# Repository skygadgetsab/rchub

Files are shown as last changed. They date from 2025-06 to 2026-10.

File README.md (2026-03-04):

# RCHub: USB-to-PPM converter with Bluetooth

RCHub lets you control
- a plane with a stick or H.O.T.A.S.;
- a car with a USB steering wheel and pedals;
- a mini-quad with a game console controller;
- and any combination of above, plus connect a [wireless bluetooth head tracker](https://github.com/ysoldak/HeadTracker)!

<table>
<tr><td>
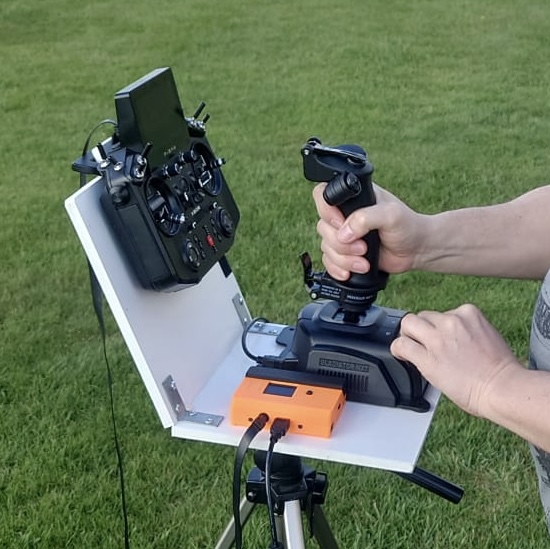
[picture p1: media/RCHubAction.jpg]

</td><td>
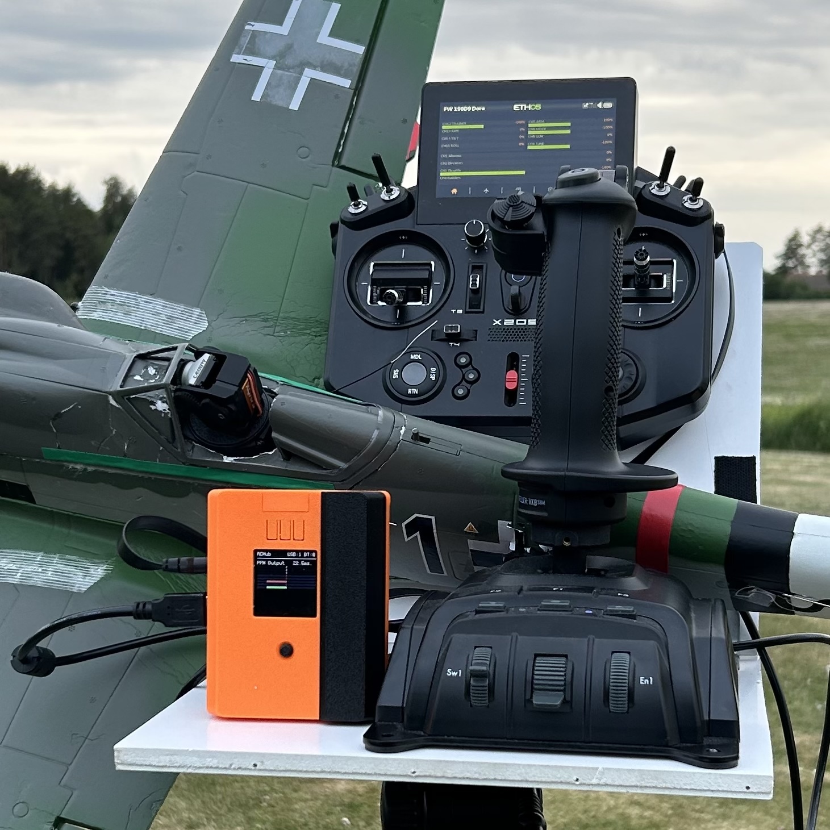
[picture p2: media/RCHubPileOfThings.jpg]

</td></tr>
</table>

## Features

- **Auto-discovery joystick devices**
  - Recognizes and pre-configures any new USB controller;
  - **Up to 8 joysticks** simultaneously.  
    _you'll need a separate USB hub for that, as RCHub has only one physical USB port._

- **Built-in display** with 5-way joystick and 3 buttons for easy configuration
  - **Up to 16 output channels** configurable directly on screen, no config file editing needed
  - **Color-coded** channel visualisations, by source
    - red - axis,
    - green - button,
    - blue - bluetooth.
  - **Raw data view** page  
    _see the raw data your joystick sends, access state of it, deadzones, axis and button numbers_

- **Bluetooth wireless PARA trainer support**  
  Automatically connects to devices that support Bluetooth PARA trainer protocol and allows you to mix in these channels to PPM output. As such, RCHub can be used as Bluetooth-to-PPM bridge for radios w/o bluetooth support. Especially convenient when used with wireless head trackers, with or without USB joystick.

- **Processing adds minimal delay**  
  Just half of the PPM frame, or approximately 10ms.

- **Simple firmware upgrades**  
  [Download latest release](https://github.com/skygadgetsab/rchub/releases) and place the `.bin` file into "app" folder on Micro SD card.

- **Fully autonomous** and provides power to connected joysticks.  
  Accepts well known and widely used **18650 Li-ion battery** (not included due to shipping restrictions).  
  Battery is optional as RCHub can be powered via USB-C from a power bank or a phone charger.

See also [FEATURES.pdf](FEATURES.pdf)

## User Manual

### Main Buttons

- **Left button** switches between 4 configuration profiles; 
- **Middle button** rotates the screen 90deg;
- **Right button** switches pages: Channels, Settings and Raw inputs.

### 5-way Joystick

This little joystick is used for page navigation and for changing and confirming values.

### Channels page

List of RC channels and their current values.

Active channels are on light gray background. Inactive channels have dark gray backround. 

Note: A channel can be inactive due to following:
  - Currently connected source (USB joystick or Bluetooth trainer) has [explicitly disabled](#channel-edit-page) the channel;
  - [RCHub is not activated](#activation), so only 4 first channels are active.

Use this page to cross-check values generated by RCHub with the values received on the other end of PPM link, in your radio.  

Here, you can also access a channel edit page:
- Select a channel with 5-way joystick by pressing it up or down;
- Enter channel edit page by pressing the joystick.

#### Channel edit page

Note: To edit a channel you have to have at least one input device connected to RCHub (USB or Bluetooth).

- Navigate channel options by using the 5-way joystick, up or down;  
- Activate an option by pressing on the joystick;  
- Edit option value by pressing up or down;  
- Finish editing an option by pressing on the joystick again;  
- Return to the main page by selecting "Save & Back..." line and pressing on the 5-way joystick.

### Raw device view page

This page shows raw data received from a connected device: for USB controllers these are axes and buttons, for Bluetooth trainer these are channels.  
Switch between raw and normalised value views with the 5-way joystick, left or right.  
Use this page to check your hardware and discover axis and button numbers.

### Settings page

Here you can select number of channels sent to your RC transmitter (radio) over PPM, up to 16.  
Be mindful, by increasing number of channels you make PPM frame larger and that adds to the delay.

Bluetooth discovery can also be enabled or disabled here. Bluetooth is disabled by default.

See also [USER_MANUAL.pdf](USER_MANUAL.pdf)

## Do It Yourself

Feeling adventurous?  
Feel free to assemble your very own RCHub yourself!

**A word of warning** before you start DIY though...  
Assembling hardware, soldering 3.5mm jack socket, even 3D priting a case is easy.  

The hard part is to make an app to start automatically on RPi boot (if you wish so), make sure no other heavy task is running on background that can affect PPM frame rate, configure OS to survive sudden loss of power (you probably want to have a simple switch to turn the thing on and off?), and other small tricks and tweaks.  

Considerable effort was made to properly configure Raspberry OS (for the best performance, to survive power-offs, etc.) on SD cards supplied with [RCHubs purchased from our shop](https://skygadgets.shop/products/rchub).  

You can also get properly configured [RCHub SD Card Image](https://skygadgets.shop/products/rchub-sd-card-image), flash your existing microSD Card and use it in your build.

Still not sure? [Contact us](https://skygadgets.shop/pages/contact) or reach out at our [Facebook group](https://www.facebook.com/groups/242161055041994).

### Hardware

You'll need at least these 3 components:
- Raspberry Pi computer (verified on [RPi Zero 2W](https://www.raspberrypi.com/products/raspberry-pi-zero-2-w/) and RPi 4)
- [Waveshare's 1.44 LCD HAT](https://www.waveshare.com/wiki/1.44inch_LCD_HAT)
- microSD card with RaspbianOS flashed on it  
  _A1 or A2 rating is recommended_

Connect PPM output signal wire to `GPIO17` and `GND` to the ground pin nearby (see Raspberry Pi pinout).

You can also DIY an exact copy of the official [RCHub](https://skygadgets.shop/products/rchub), see "X306" folder.

### Software

Download latest `.bin` [release](https://github.com/skygadgetsab/rchub/releases) file, place it into `app` folder on Micro SD card.  
The folder is visible as `/boot/firmware/app` from inside running RPi, so run the application from there.  

### Activation

By default, the application runs in **demo mode** and output is limited to 4 PPM channels.  
In all other aspects the application is fully functional.  
You are free to use "unactivated" device forever, as long as 4 output channels is enough for you (for basic flying AETR is quite enough).

See [DEMO.txt](DEMO.txt) for more information and Q&A.

Please, [contact SkyGadgets](https://skygadgets.shop/pages/contact) to obtain an activation key for your device and unlock all 16 channels.

## Contacts

- Website: https://skygadgets.shop/pages/contact
- Discord: https://discord.gg/qg5zTtx3EQ
- Facebook: https://www.facebook.com/groups/242161055041994

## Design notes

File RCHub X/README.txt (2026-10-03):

This folder contains all necessary to assemble your own RCHub X.

In STL folder you find files to for 3D printed case.
Raspberry Pi 5 board - choose "RPi 5". 
Raspberry Pi 4B board - choose "RPi 4".
Raspberry Pi 3B board - choose "Back RPi 5" and "Spacer Back RPi 4".

Wiring is the same as in case of X306, just much less parts: only 1.44 inch display and 3.5mm AUX socket is required.

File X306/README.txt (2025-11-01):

# RCHub Do-It-Yourself Guide (Geekworm X306 UPS Shield)

This guide shall help you assemble your very own RCHub based on Geekworm X306 UPS Shield.

Start with BOM.txt, it contains list of all parts you need to build an exact copy of the fully assembled RCHub available on our shop.
You don't have to make an exact copy, though. The RCHub firmware shall run on any modern Raspberry Pi (3, 3B, 4, Zero 2W).
The only requrement is Waveshare 1.44inch LCD Display Hat -- you need it to see runtime state of RCHub and be able to configure it.
We also recommend you use A1 or A2 rated microSD card.

3D printed enclosure (see STL folder) is optimized for X306 UPS Shield, USB adapters, 3.5mm Audio Socket and a main switch, all listed in BOM.txt
So, print the enclosure and having all parts from BOM.txt list proceed to assembly.

WIRING.pdf and ASSEMBLY.txt shall help you assemble RCHub and install firmware on SD Card.

Consult USER_MANUAL.pdf to learn how to use RCHub.

By default, RChub starts in DEMO mode (limited to 4 output channels), and need to be activated to unlock all 16 output channels.
Please, read DEMO.txt and contact us, so we can help you unlock your device.

Good luck, have fun printing and assembling your very own RCHub! 
Enjoy flying or driving your RC model with an USB controller.

Share your success and ask questions on our Facebook group https://www.facebook.com/groups/242161055041994

## Fully assembled
----------------------------

Do not feel like DIY after all?
Order fully assembled, unlocked and tested RCHub directly from our webshops: https://skygadgets.shop/ or https://skygadgets.etsy.com/

## Contacts
----------------------------

Please feel free to drop a message to author on email address below if you have any questions or suggestions.
And/or join our Facebook group.

Contact and support: ysoldak@gmail.com
Facebook group: https://www.facebook.com/groups/242161055041994
Webshops: https://skygadgets.shop/ or https://skygadgets.etsy.com/

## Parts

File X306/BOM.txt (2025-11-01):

Bill Of Materials (BOM)
=======================

Raspberry Pi Zero 2W      | https://www.raspberrypi.com/products/raspberry-pi-zero-2-w/ | Try source with headers soldered
Geekworm X306 UPS Shield  | https://wiki.geekworm.com/X306                              | Modification needed! See WIRING.pdf
Waveshare 1.44" LCD HAT   | https://www.waveshare.com/1.44inch-lcd-hat.htm
Battery Li-Ion 18650 3.7v | https://en.wikipedia.org/wiki/18650_battery
MicroSD Card (A1 or A2)   | https://www.kingston.com/en/memory-cards/canvas-select-plus-microsd-card-sdcs3

Micro USB Adapter          | https://www.amazon.se/dp/B0CCJC1VV9/             | Joystick input
3.5mm Jack Socket          | https://www.amazon.se/dp/B0BGQ5X9X8/             | PPM output
USB-C 90deg Adapter        | https://www.amazon.se/dp/B09C8JP8HK/             | Charging or powering w/o battery
Switch 6 Pin 2 Pos DPDT    | https://www.amazon.se/dp/B0DY5VBQFJ/             | Physically cuts off battery
Audo Cable with 3.5mm Jack | https://www.amazon.se/dp/B088CZLHGL/             | Any good quality mono or stereo audio cable will do

4xM2.5x12 & 6xM2x6 Bolts    |
8xM2.5 & 6xM2 Brass Inserts | https://cnckitchen.store/collections/threaded-inserts | For 3D printed parts

3D printed case, see STL folder and ASSEMBLY.txt

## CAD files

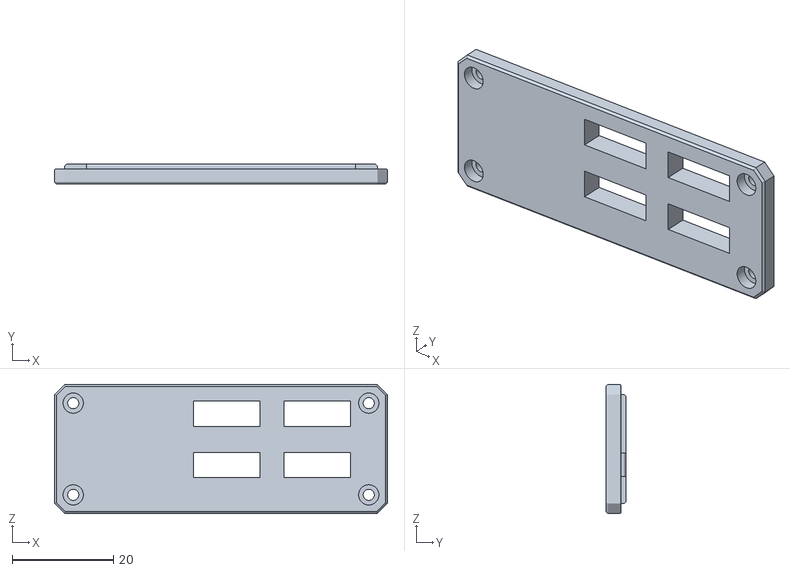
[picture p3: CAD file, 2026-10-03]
RCHub X/STL/RCHub X - Back RPi 5.stl
65.8 x 4.00 x 25.5

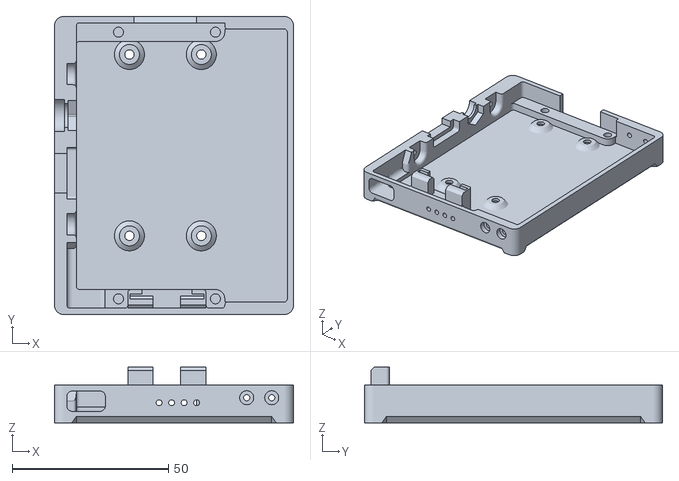
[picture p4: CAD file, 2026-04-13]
X306/STL/Enclosure Bottom.stl
76.5 x 95.3 x 17.8

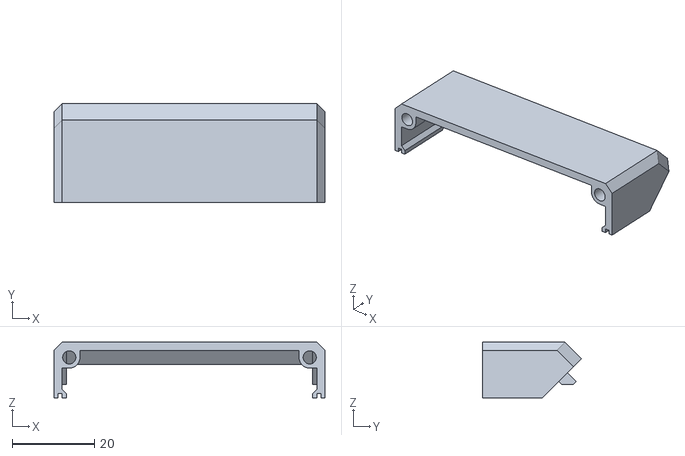
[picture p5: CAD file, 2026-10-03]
RCHub X/STL/RCHub X - Top Higher.stl
65.8 x 24.0 x 13.5

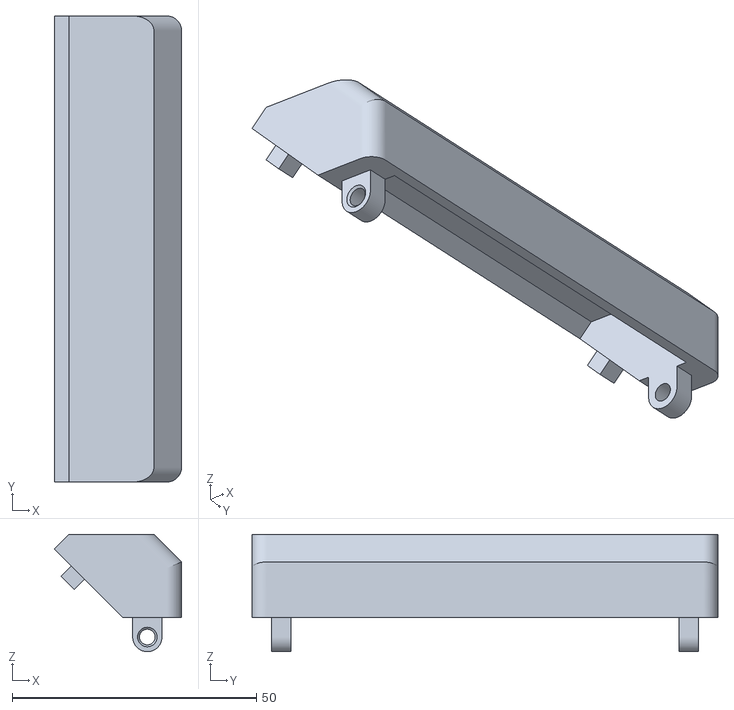
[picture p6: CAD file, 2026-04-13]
X306/STL/Battery Cover.stl
26.0 x 95.3 x 24.0

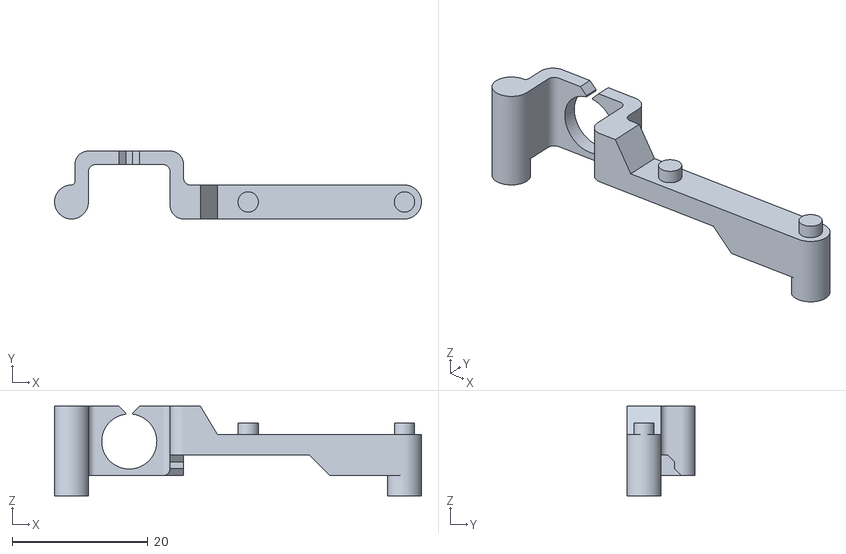
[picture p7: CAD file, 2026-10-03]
RCHub X/STL/RCHub X - Spacer Front.stl
54.0 x 10.0 x 13.2

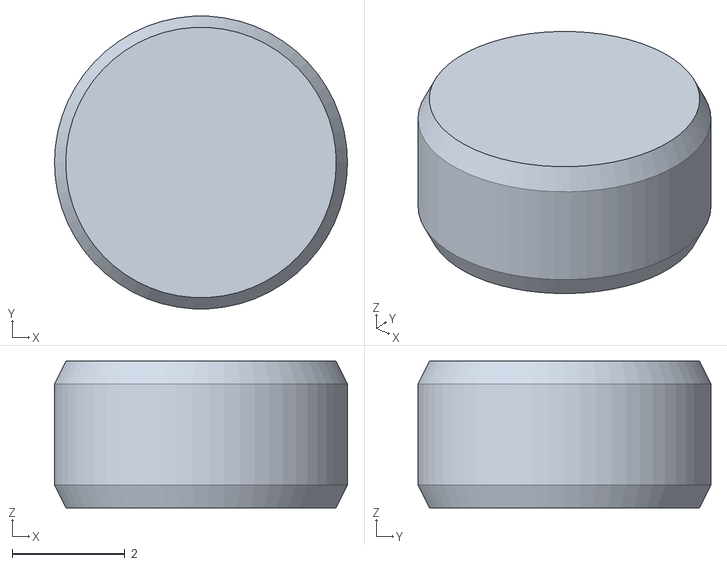
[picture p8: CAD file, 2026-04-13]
X306/STL/Joystick Hat.stl
5.20 x 5.19 x 2.60

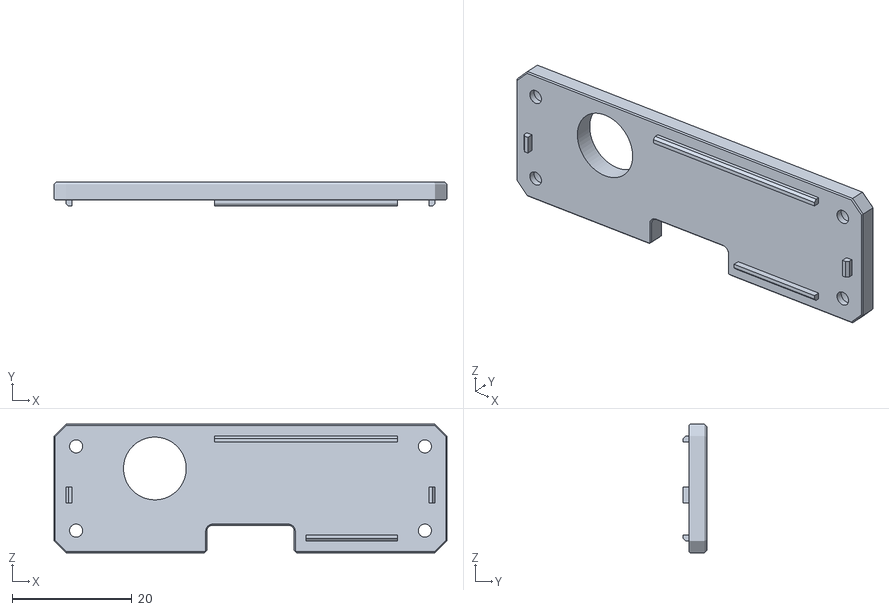
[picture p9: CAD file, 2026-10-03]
RCHub X/STL/RCHub X - Front.stl
65.8 x 4.00 x 21.5

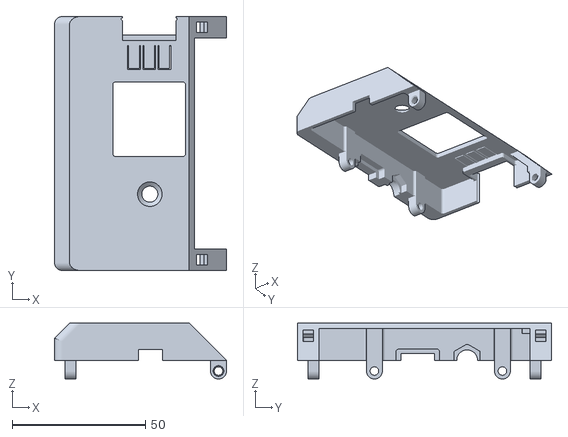
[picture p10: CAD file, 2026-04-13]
X306/STL/Enclosure Top.stl
64.5 x 95.3 x 21.0

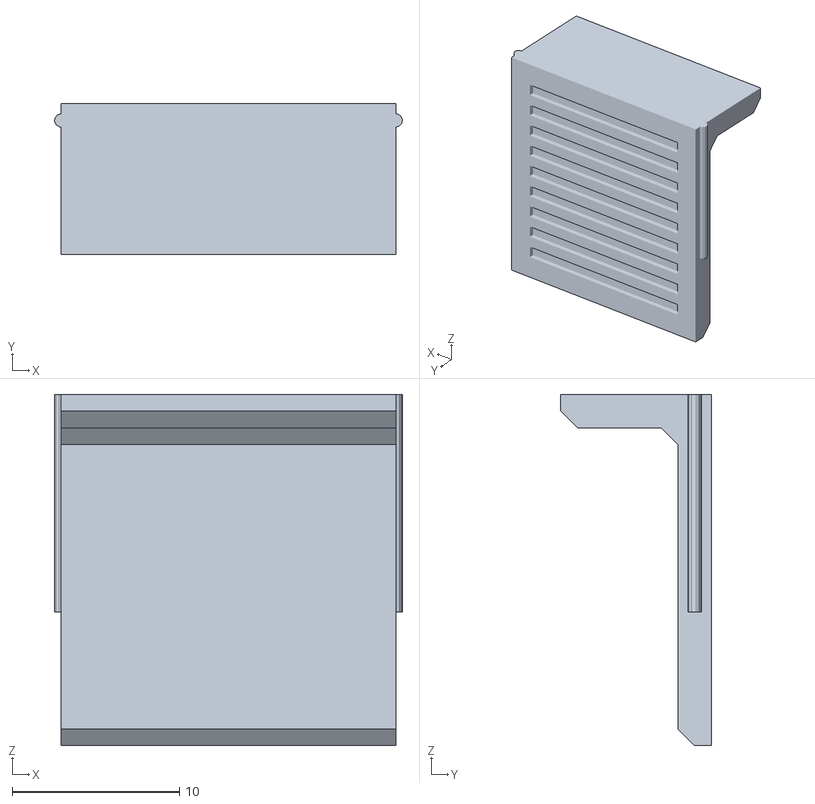
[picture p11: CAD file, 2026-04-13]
X306/STL/SD Card Cover.stl
20.8 x 9.00 x 21.0

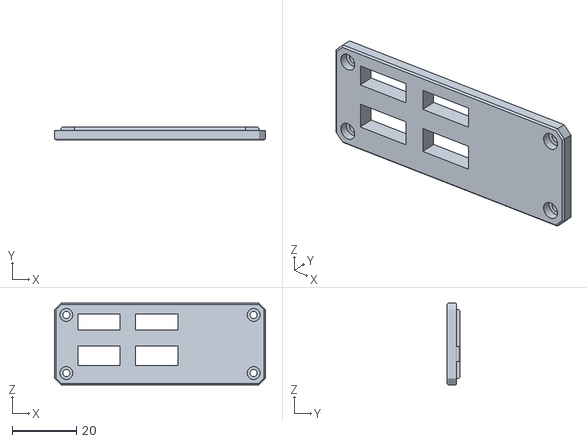
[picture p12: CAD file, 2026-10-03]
RCHub X/STL/RCHub X - Back RPi 4.stl
65.8 x 4.00 x 25.5

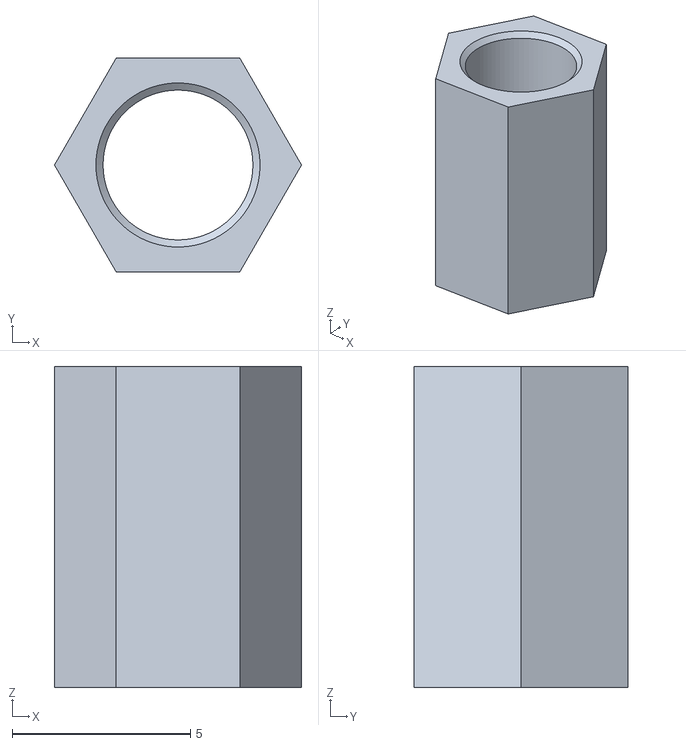
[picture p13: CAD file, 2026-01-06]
X306/STL/Display Standoff 9mm.stl
6.93 x 6.00 x 9.00

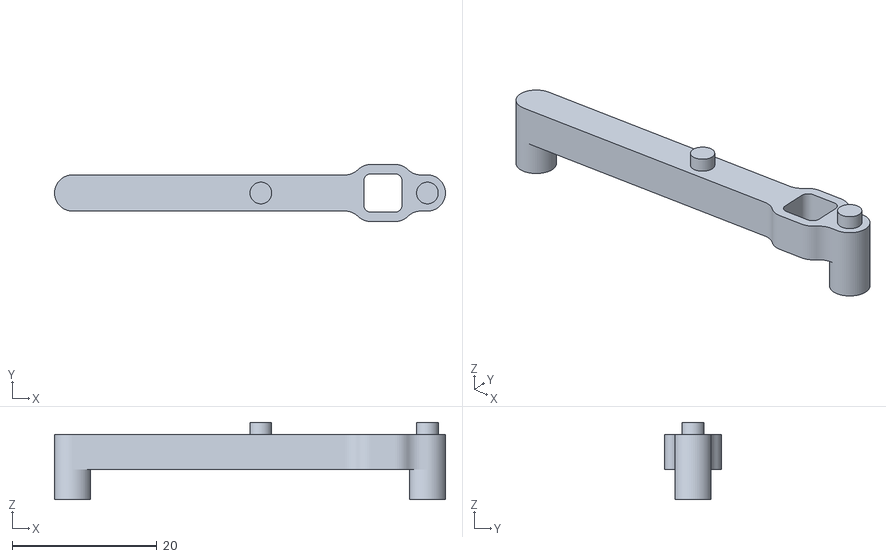
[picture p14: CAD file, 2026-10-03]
RCHub X/STL/RCHub X - Spacer Back RPi 4.stl
54.0 x 7.90 x 10.7

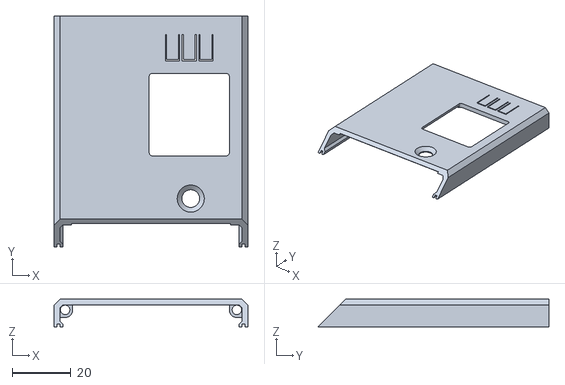
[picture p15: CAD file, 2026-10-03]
RCHub X/STL/RCHub X - Top Lower.stl
65.8 x 78.4 x 9.50

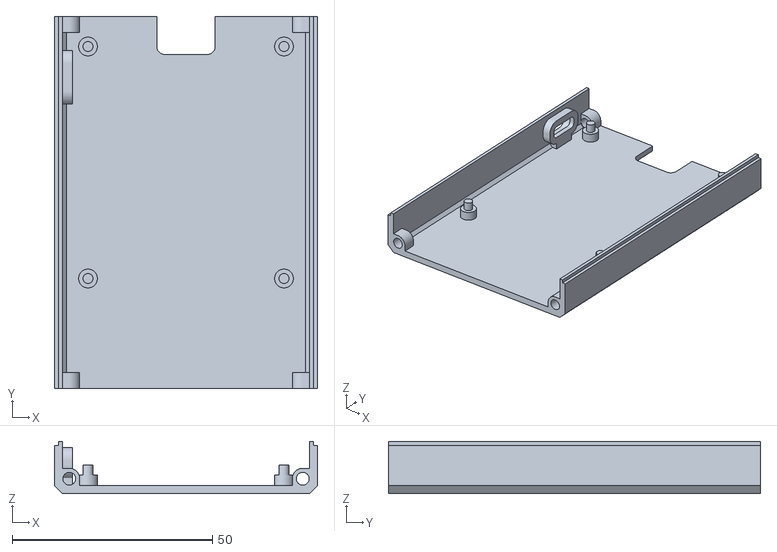
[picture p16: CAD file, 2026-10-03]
RCHub X/STL/RCHub X - Bottom.stl
65.8 x 93.0 x 13.0

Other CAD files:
RCHub X/STL/RCHub X - Joystick Hat.stl
RCHub X/STL/RCHub X - Spacer Back RPi 5.stl

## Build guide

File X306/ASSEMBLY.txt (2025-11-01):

Assembly
============================

3D Print the Enclosure
----------------------------

Nozzle: 0.2 to 0.4
Layer height: 0.1 to 0.2
Supports: no
Material: PLA, PETG or ABS

Please calibrate your printer to ensure dimensional accuracy before printing.  
Properly calibrated printer also helps you avoid most of post-processing.

Print all parts in STL folder. You'll need 4 (four) pieces of Display Standoff 8mm.  

Hardware
----------------------------

For successful assembly, you need all hardware parts listed in the Bill of Materials, see BOM.txt

Source them or analogs at your favourite shop; Amazon usually has them all.

For the wiring and assembly tips, see WIRING.pdf

Firmware
----------------------------

Do not have RCHub SD Card Image? Download it here: https://skygadgets.shop/products/rchub-sd-card-image

Flash downloaded RCHub SD Card Image to MicroSD Card with help of Raspberry Pi Imager (or analog).
https://www.raspberrypi.com/software/

IMPORTANT!
Simply copying over the image file to the SD Card will not work, the image need to be flashed.

Insert the SD Card to the RCHub and power it on. The very first time may take a bit of time, 
please be patient and do not switch the device off.
The RCHub is fully initialised when you see the channels page after RCHub boot screen.
Now it is safe to power off.

See USER_MANUAL.pdf for further instructions.

An alternative to the RCHub SD Card Image is to run freely avaialble RCHub binary on any manually configured Raspberry Pi.
Download the binary from GitHub here: https://github.com/skygadgetsab/rchub

Unlock full functionality
----------------------------

By default, RCHub starts in DEMO mode -- output is limited to 4 channels.
Otherwise it is a fully functional mode that lets you test compatibility of your hardware with RCHub.
For some, 4 channels may be enough, feel free to use RCHub in DEMO mode for as long as you need.

To unlock all 16 channels, please contact us (see README.txt) and we help you activate your RCHub.

See DEMO.txt for more information.

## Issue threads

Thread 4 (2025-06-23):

Redesign Raw Device Page to fit more data

ysoldak, 2025-06-23:
So more axes and buttons can be shown.

Alternatively, add scrolling to that page.

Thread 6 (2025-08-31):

When using inputs from multiple usb devices ie. USB1(Hotas Joystick) USB2(Hotas Throttle) axes overap and cannot be bound separately in channels.

SilentZen, 2025-08-31:
When using inputs from multiple usb devices ie. USB1(Hotas Joystick) USB2(Hotas Throttle) axes overap and cannot be bound separately in channels.
Axes need to be unique across all input devices, maybe have first USB device start from 1 on axes then USB2 from 33 and USB3 65.
This issue may also happen with buttons, although my second sevice buttons never seemed to be discovered.
USB order needs to be maintained, could devices be ordered based on a unique hardware identifier of attached devices?

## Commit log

2025-11-01 X306 DIY Guide and STLs
    [Battery Cover.stl, Display Standoff 8mm.stl, Enclosure Bottom.stl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]
2026-01-06 STLs updated to fit X306 v1.5
    [Battery Cover.stl, Display Standoff 8mm.stl, Display Standoff 9mm.stl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]
2026-01-07 Enclosure Top align with display
    [Enclosure Top.stl]
2026-02-15 Update left button functionality in README
2026-04-13 Update STLs
    [Battery Cover.stl, Enclosure Bottom.stl, Enclosure Top.stl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]
2026-04-13 Use current date for packaging
2026-10-03 RCHub X case
    [RCHub X - Back RPi 4.stl, RCHub X - Back RPi 5.stl, RCHub X - Bottom.stl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]
